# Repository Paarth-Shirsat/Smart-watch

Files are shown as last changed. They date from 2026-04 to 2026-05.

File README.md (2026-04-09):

# Smart-Watch (ESP32-PICO-D4)

A comprehensive open-source smart-watch project featuring high-end sensors, GPS integration, and a sleek hardware design. This project is built around the **ESP32-PICO-D4** System-in-Package, providing a compact yet powerful core for wearable applications.

<p align="center">
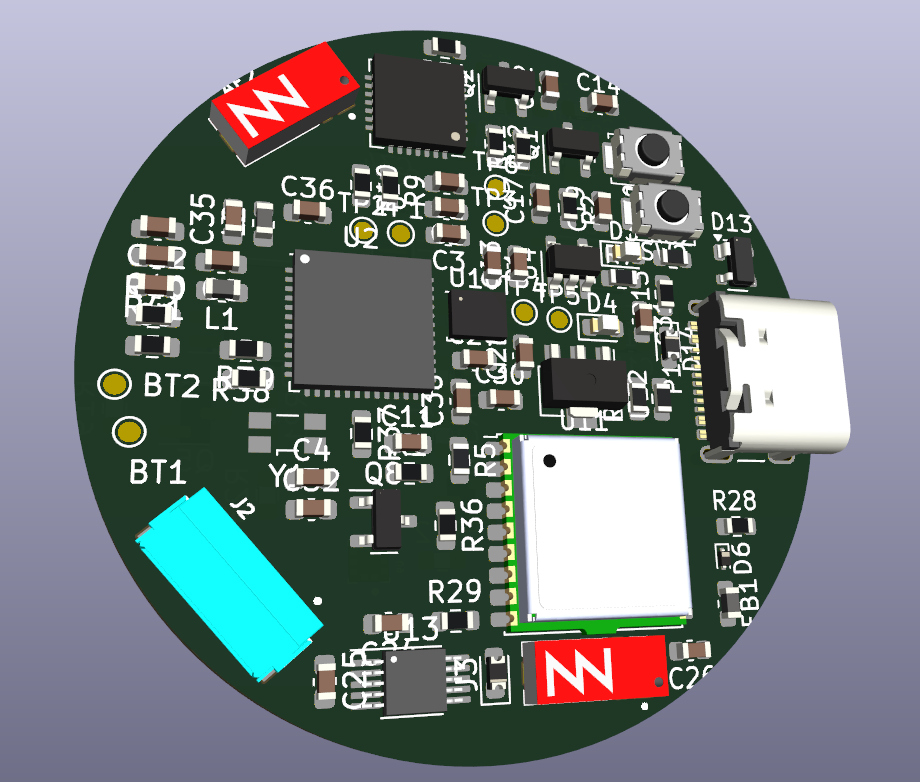
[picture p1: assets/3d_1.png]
  
</p>
<p align="center">
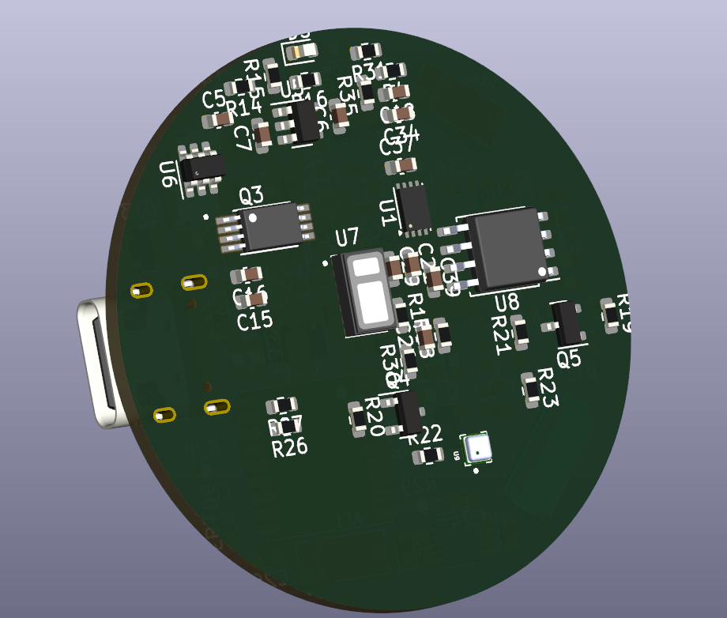
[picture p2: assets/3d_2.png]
  
</p>
## 🚀 Features

- **Core Processor**: ESP32-PICO-D4 (Dual-core, Wi-Fi & Bluetooth, integrated Flash).
- **Navigation**: u-blox **MAX-M10S** GNSS module for high-precision positioning.
- **Health Monitoring**: **MAX30102/30105** sensor for heart rate and pulse oximetry.
- **Motion Tracking**: **LSM6DSO/LSM6DS3** 6-axis IMU (Accelerometer + Gyroscope).
- **Environment**: **BMP388** barometric pressure sensor for altitude and weather tracking.
- **Haptics**: **DRV2605L** haptic driver for sophisticated vibration patterns.
- **Storage & Memory**: 
  - 128Mbit external SPI Flash (**W25Q128**).
  - 64Mbit external QSPI PSRAM (**APS6404L**).
- **Power Management**:
  - USB-C charging via **MCP73831** Li-Po charger.
  - Integrated battery protection using **AP9101C**.
  - High-efficiency LDOs for stable rail regulation.
- **Connectivity**: USB-to-UART via **CP2102N** for easy programming and debugging.

## 📂 Repository Structure

```text
├── firmware/                 # ESP-IDF based driver  implementations and test apps
│   ├── bmp388/               # Barometric sensor test code
    ├── lsm6dso_i2c/          # 6-axis IMU I2C    
    |
    ├── max30102/             # Heart rate sensor 
    └── max_m10s/             # GNSS/GPS driver and esting
├── PCB_Files/                # KiCad Hardware Design Files
│   ├── watch.kicad_sch       # Main Schematic
│   ├── watch.kicad_pcb       # PCB Layout
│   └── watch.csv             # Bill of Materials (BOM)
└── footprints_schematics/    # Custom KiCad libraries and footprints
```

## 🛠️ Hardware Setup

The hardware is designed using **KiCad**. You can find the full schematics and PCB layout in the `PCB_Files` directory.

### Key Components
- **MCU**: [ESP32-PICO-D4](https://www.espressif.com/sites/default/files/documentation/esp32-pico-d4_datasheet_en.pdf)
- **GNSS**: [u-blox MAX-M10S](https://content.u-blox.com/sites/default/files/MAX-M10S_DataSheet_UBX-20035208.pdf)
- **IMU**: [ST LSM6D3](https://www.st.com/resource/en/datasheet/lsm6ds3tr-c.pdf)
- **Pressure**: [Bosch BMP388](https://www.bosch-sensortec.com/media/boschsensortec/downloads/datasheets/bst-bmp388-ds001.pdf)

## 💻 Firmware Development

The firmware is developed using the **ESP-IDF** (Espressif IoT Development Framework).

### Prerequisites
- Install [ESP-IDF SDK](https://docs.espressif.com/projects/esp-idf/en/latest/esp32/get-started/index.html) (v4.4 or later recommended).

### Building a Component
To build and flash one of the test apps (e.g., the GPS module):
```bash
cd firmware/max_m10s
idf.py build
idf.py -p [PORT] flash monitor
```

## 🎨 Design Aesthetics
The PCB design focuses on a compact circular/watch-friendly form factor with optimized trace routing for high-speed signals (Flash/PSRAM) and sensitive analog paths (Heart Rate sensor).

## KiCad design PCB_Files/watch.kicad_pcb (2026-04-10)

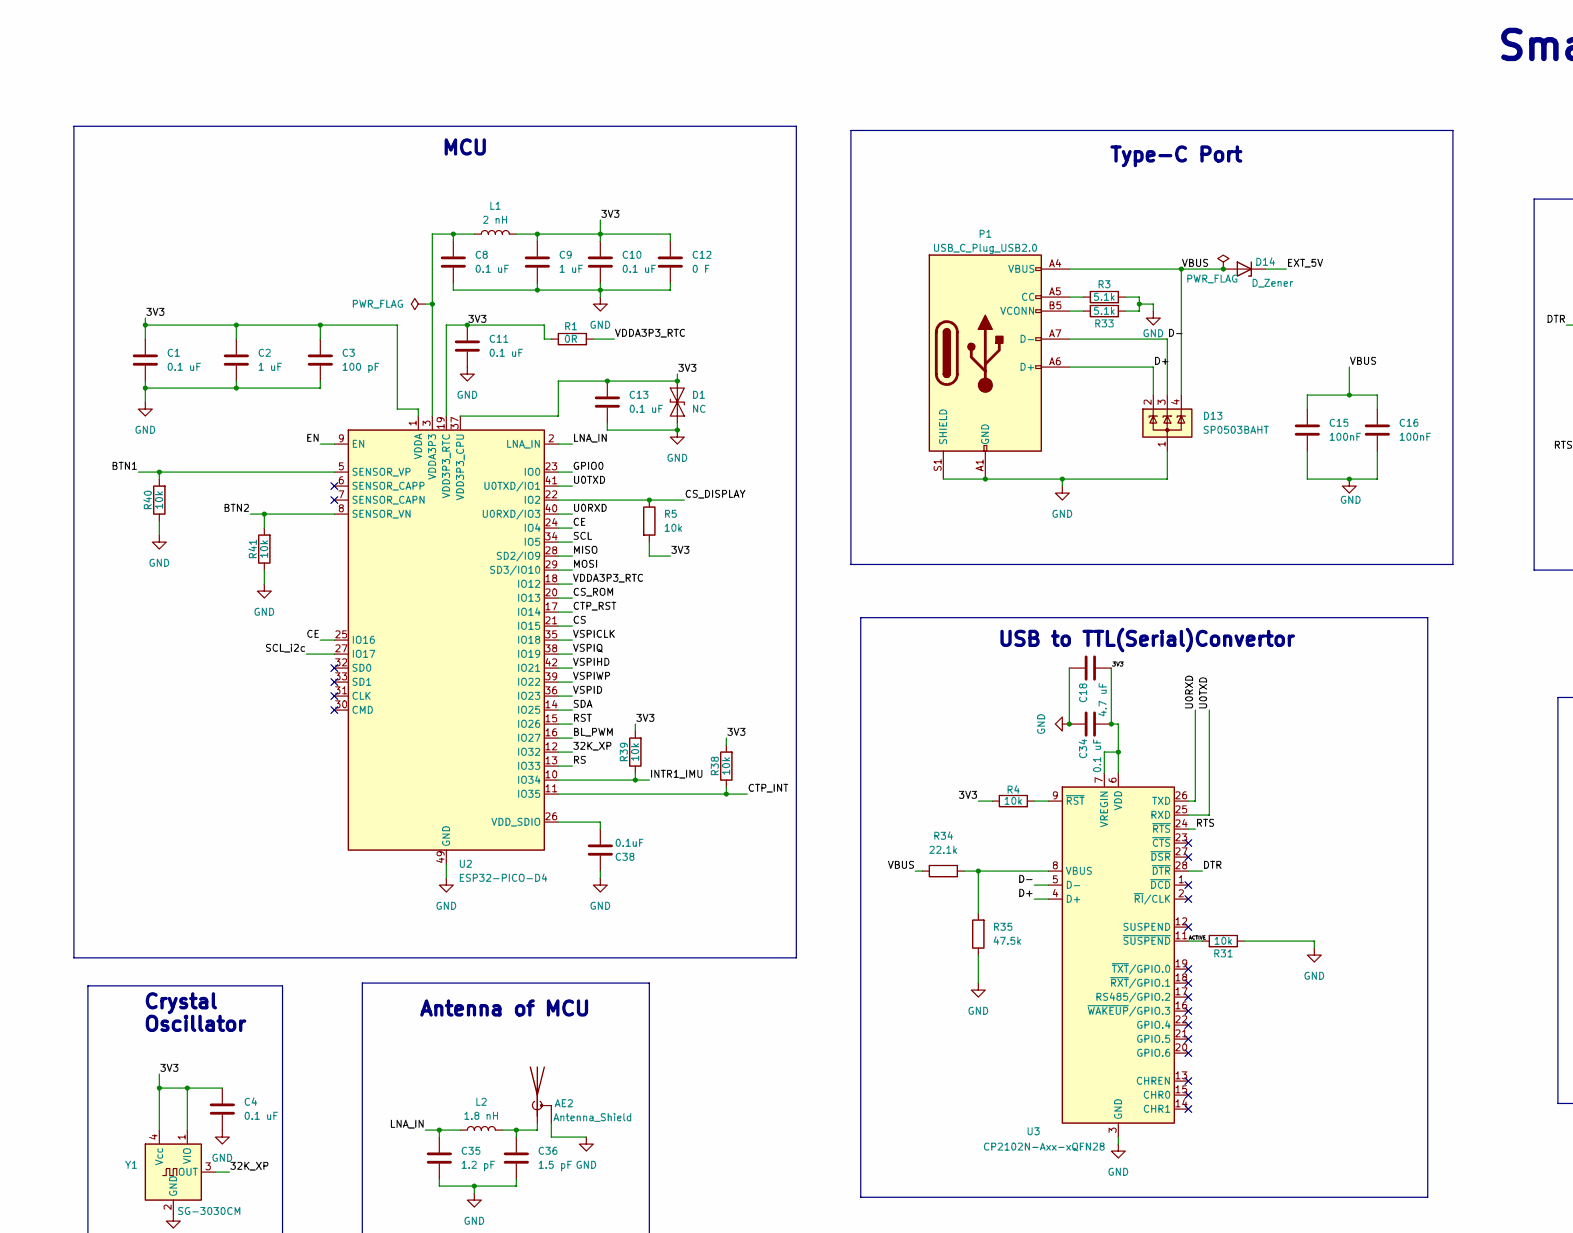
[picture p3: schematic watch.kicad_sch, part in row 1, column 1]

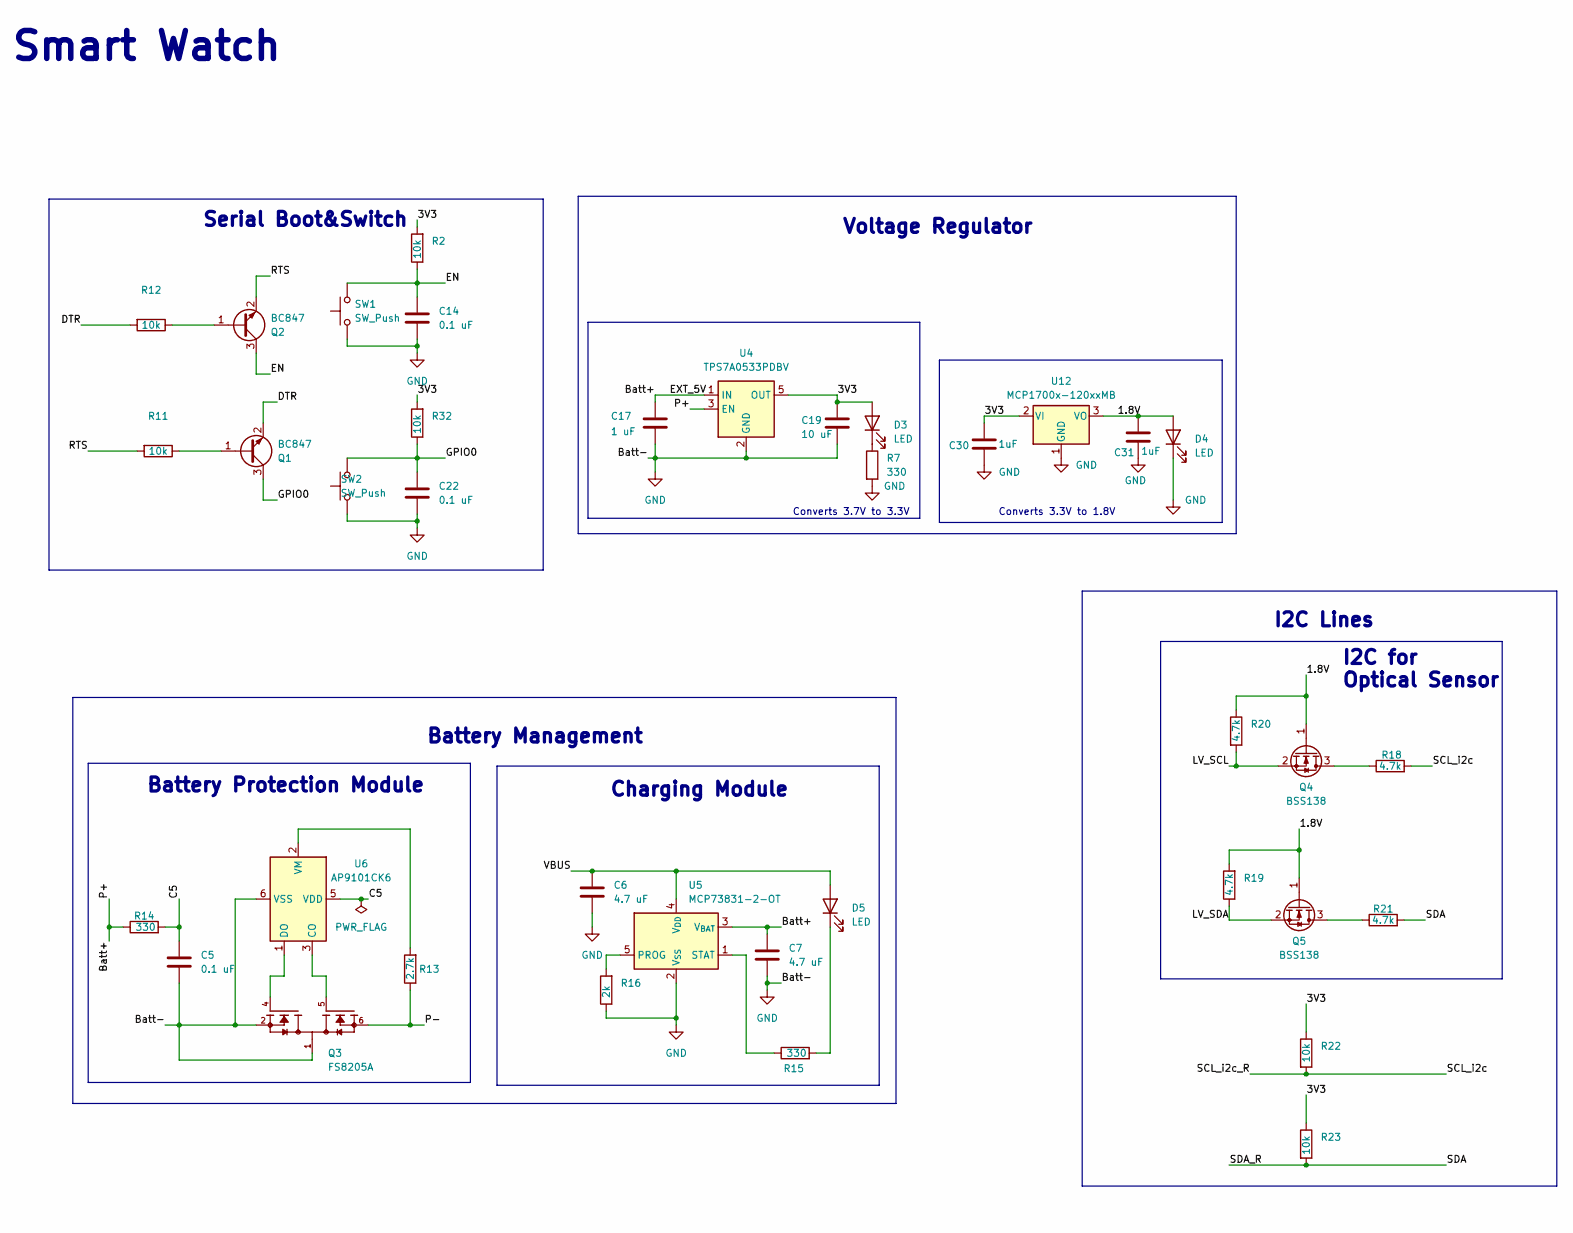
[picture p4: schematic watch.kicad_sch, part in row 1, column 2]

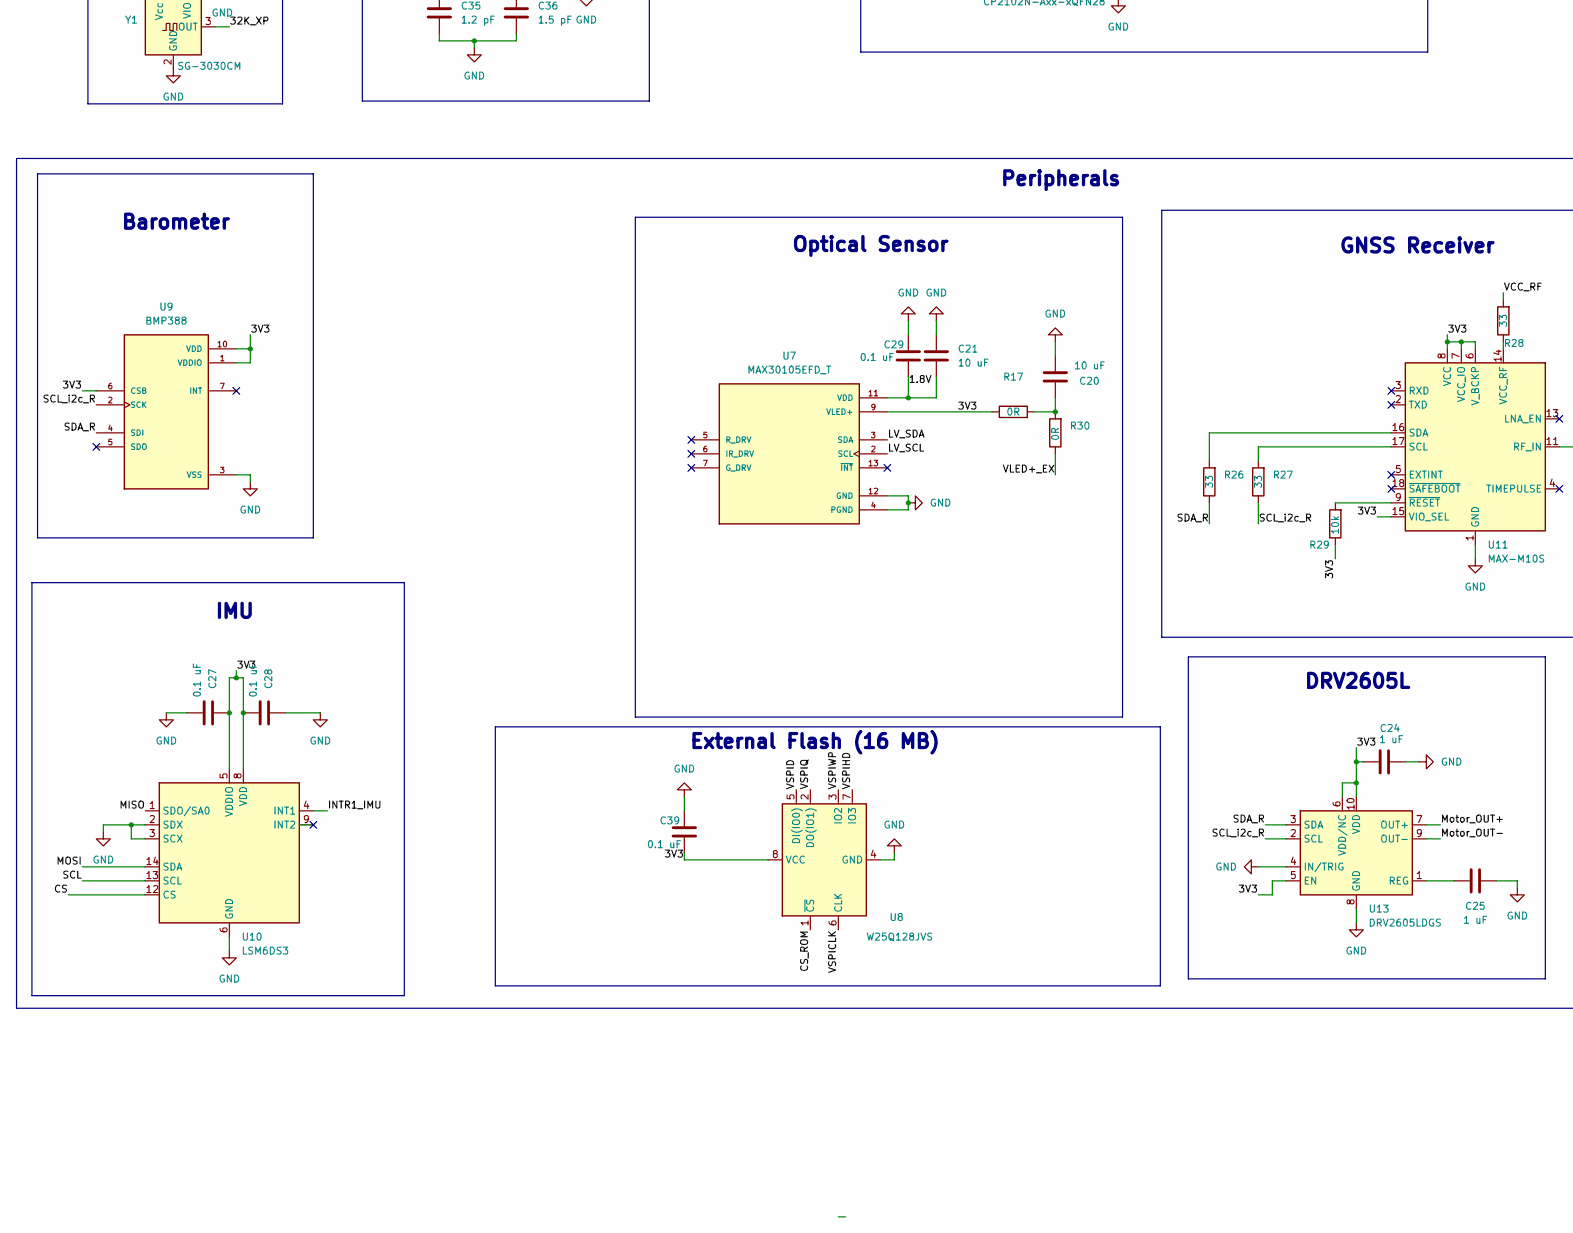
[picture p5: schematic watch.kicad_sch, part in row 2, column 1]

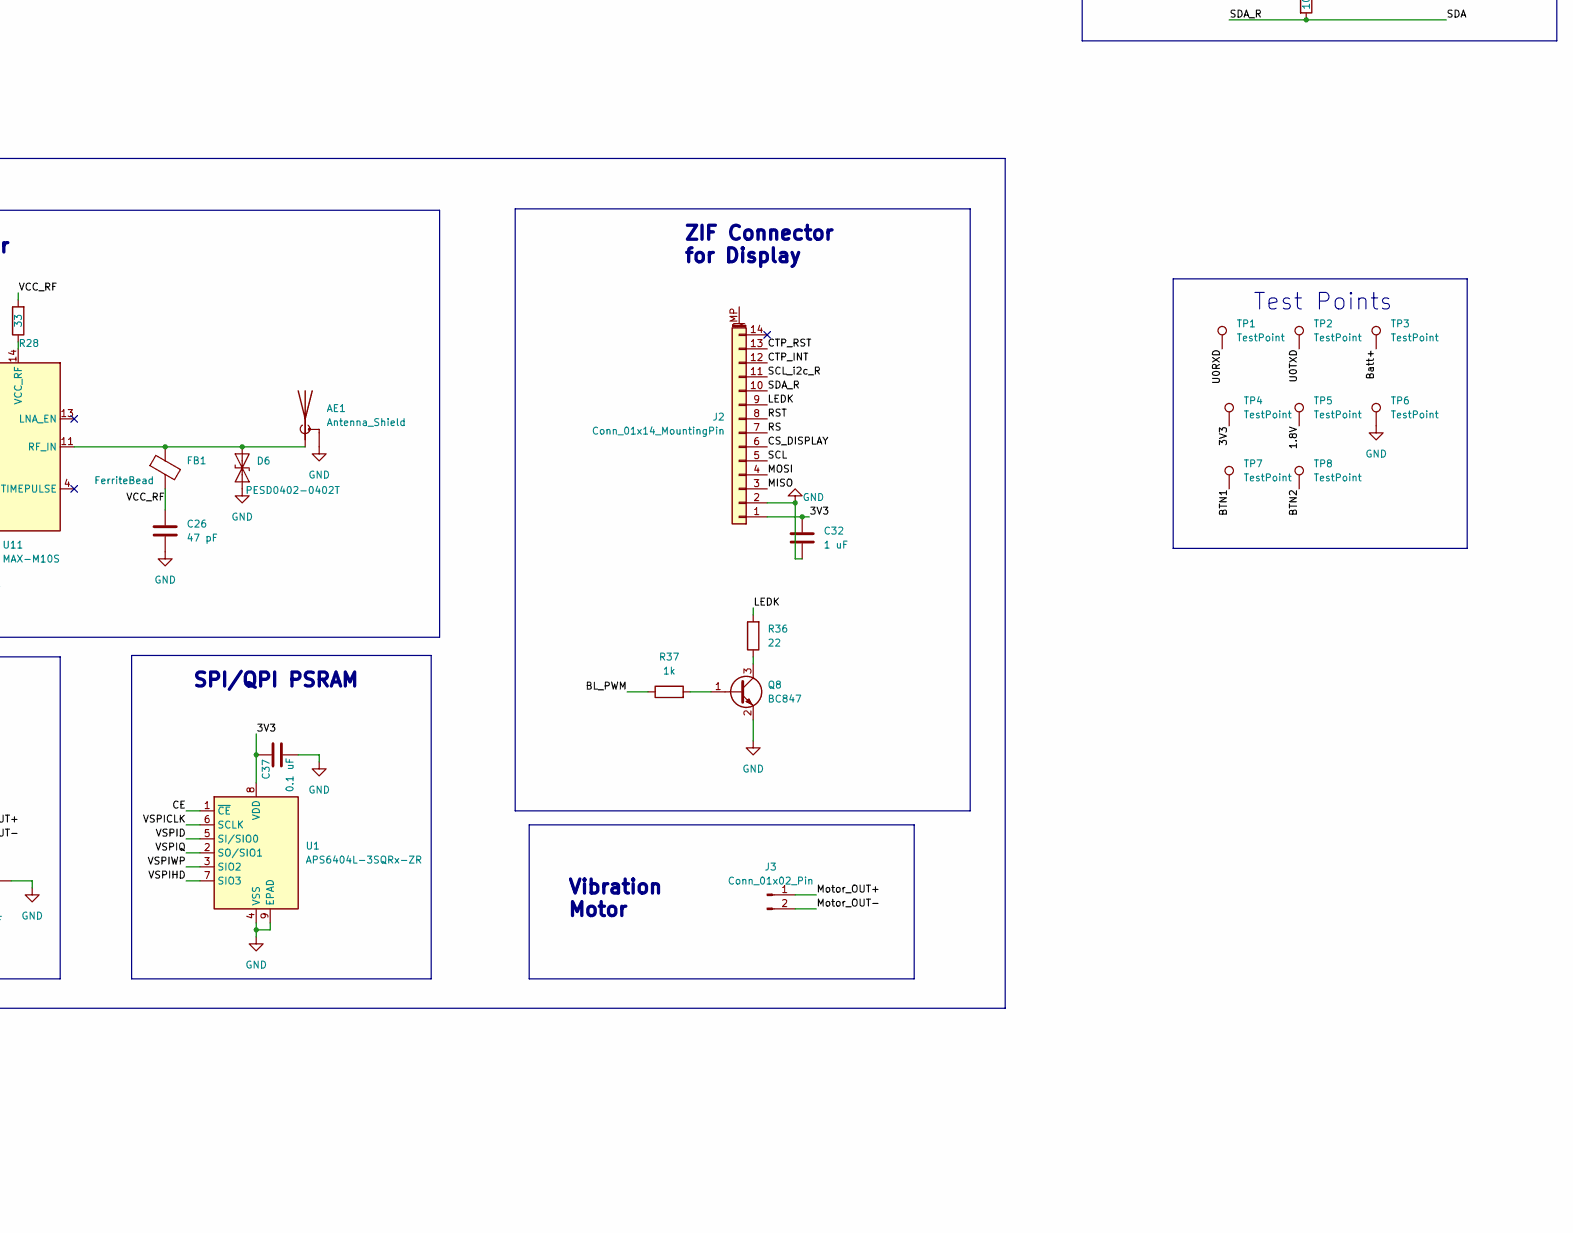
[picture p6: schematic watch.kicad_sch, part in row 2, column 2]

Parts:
AE1, AE2: Antenna_Shield; XCVR_NN03-320
C1, C4, C5, C8, C10, C11, C13, C14, C22, C27, C28, C29, C34, C37, C39: 0.1 uF; C_0603_1608Metric
C2, C9, C17, C24, C25, C32: 1 uF; C_0603_1608Metric
C3: 100 pF; C_0603_1608Metric
C6, C7, C18: 4.7 uF; C_0603_1608Metric
C12: 0 F; C_0603_1608Metric
C15, C16: 100nF; C_0603_1608Metric
C19, C20, C21: 10 uF; C_0603_1608Metric
C26: 47 pF; C_0603_1608Metric
C30, C31: 1uF; C_0603_1608Metric
C35: 1.2 pF; C_0603_1608Metric
C36: 1.5 pF; C_0603_1608Metric
C38: 0.1uF; C_0603_1608Metric
D1: NC; C_0603_1608Metric
D3, D4, D5: LED; LED_0603_1608Metric
D6: PESD0402-0402T; D_SOD-923
D13: SP0503BAHT; SOT-143
D14: D_Zener; D_0603_1608Metric
FB1: FerriteBead; L_0603_1608Metric
J2: Conn_01x14_MountingPin; HRS_FH34SRJ-14S-0.5SH_50_
J3: Conn_01x02_Pin; D_0603_1608Metric
L1: 2 nH; L_0603_1608Metric
L2: 1.8 nH; L_0603_1608Metric
P1: USB_C_Plug_USB2.0; USB_C_Receptacle_GCT_USB4105-xx-A_16P_TopMnt_Horizontal
Q1, Q2, Q8: BC847; SOT-23
Q3: FS8205A; SOP65P640X120-8N
Q4, Q5: BSS138; SOT-23
R1, R17, R30: 0R; R_0603_1608Metric
R2, R4, R5, R11, R12, R22, R23, R29, R31, R32, R38, R39, R40, R41: 10k; R_0603_1608Metric
R3, R33: 5.1k; R_0603_1608Metric
R7, R14, R15: 330; R_0603_1608Metric
R13: 2.7k; R_0603_1608Metric
R16: 2k; R_0603_1608Metric
R18, R19, R20, R21: 4.7k; R_0603_1608Metric
R26, R27, R28: 33; R_0603_1608Metric
R34: 22.1k; R_0603_1608Metric
R35: 47.5k; R_0603_1608Metric
R36: 22; R_0603_1608Metric
R37: 1k; R_0603_1608Metric
SW1, SW2: SW_Push; SW_Push_SPST_NO_Alps_SKRK
TP1, TP2, TP3, TP4, TP5, TP6, TP7, TP8: TestPoint; TestPoint_Pad_D1.0mm
U1: APS6404L-3SQRx-ZR; Winbond_USON-8-1EP_3x2mm_P0.5mm_EP0.2x1.6mm
U2: ESP32-PICO-D4; QFN-48-1EP_7x7mm_P0.5mm_EP5.3x5.3mm
U3: CP2102N-Axx-xQFN28; QFN-28-1EP_5x5mm_P0.5mm_EP3.35x3.35mm
U4: TPS7A0533PDBV; SOT-23-5
U5: MCP73831-2-OT; SOT-23-5
U6: AP9101CK6; SOT-23-6
U7: MAX30105EFD_T; 14-OESIP
U8: W25Q128JVS; SOIC-8_5.23x5.23mm_P1.27mm
U9: BMP388; PQFN50P200X200X80-10N
U10: LSM6DS3; LGA-14_3x2.5mm_P0.5mm_LayoutBorder3x4y
U11: MAX-M10S; ublox_MAX
U12: MCP1700x-120xxMB; SOT-89-3
U13: DRV2605LDGS; VSSOP-10_3x3mm_P0.5mm
Y1: SG-3030CM; Oscillator_SMD_SeikoEpson_SG3030CM

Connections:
/1.8V: C21.2, C29.2, C31.2, D4.2 (A), Q4.1 (G), Q5.1 (G), R19.2, R20.1, TP5.1, U7.11 (VDD), U12.3 (VO)
/3V3: C1.1, C2.1, C3.1, C4.1, C9.1, C10.1, C11.1, C12.1, C13.1, C18.2, C19.1, C24.1, C27.1, C28.2, C30.2, C32.1, C34.2, C37.1, C39.2, D1.2 (A2), D3.2 (A), J2.1, L1.2, R1.1, R2.2, R4.1, R5.2, R17.1, R22.1, R23.1, R29.1, R32.2, R38.2, R39.2, TP4.1, U1.8 (VDD), U2.1 (VDDA), U2.19 (VDD3P3_RTC), U2.37 (VDD3P3_CPU), U2.43 (VDDA), U2.46 (VDDA), U3.6 (VDD), U3.7 (VREGIN), U4.5 (OUT), U7.9 (VLED+), U8.8 (VCC), U9.1 (VDDIO), U9.6 (CSB), U9.10 (VDD), U10.5 (VDDIO), U10.8 (VDD), U11.6 (V_BCKP), U11.7 (VCC_IO), U11.8 (VCC), U11.15 (VIO_SEL), U12.2 (VI), U13.5 (EN), U13.6 (VDD/NC), U13.10 (VDD), Y1.1 (VIO), Y1.4 (Vcc)
/32K_XP: U2.12 (IO32), Y1.3 (OUT)
/ACTIVE: R31.2, U3.11 (~SUSPEND)
/BL_PWM: R37.1, U2.16 (IO27)
/BTN1: R40.2, TP7.1, U2.5 (SENSOR_VP)
/BTN2: R41.2, TP8.1, U2.8 (SENSOR_VN)
/Batt+: C7.1, C17.1, D14.1 (K), R14.1, TP3.1, U4.1 (IN), U4.3 (EN), U5.3 (V_{BAT})
/C5: C5.1, R14.2, U6.5 (VDD)
/CE: U1.1 (~CE), U2.24 (IO4), U2.25 (IO16)
/CS: U2.21 (IO15), U10.12 (CS)
/CS_DISPLAY: J2.6, R5.1, U2.22 (IO2)
/CS_ROM: U2.20 (IO13), U8.1 (~CS)
/CTP_INT: J2.12, R38.1, U2.11 (IO35)
/CTP_RST: J2.13, U2.17 (IO14)
/D+: D13.2 (K), P1.A6 (D+), U3.4 (D+)
/D-: D13.3 (K), P1.A7 (D-), U3.5 (D-)
/DTR: Q1.2 (E), R12.2, U3.28 (~DTR)
/EN: C14.1, Q2.3 (C), R2.1, SW1.2, U2.9 (EN)
/GPIO0: C22.1, Q1.3 (C), R32.1, SW2.2, U2.23 (IO0)
/INTR1_IMU: R39.1, U2.10 (IO34), U10.4 (INT1)
/LEDK: J2.9, R36.2
/LNA_IN: C35.1, L2.1, U2.2 (LNA_IN)
/LV_SCL: Q4.2 (S), R20.2, U7.2 (SCL)
/LV_SDA: Q5.2 (S), R19.1, U7.3 (SDA)
/MISO: J2.3, U2.28 (SD2/IO9), U10.1 (SDO/SA0)
/MOSI: J2.4, U2.29 (SD3/IO10), U10.14 (SDA)
/Motor_OUT+: J3.1, U13.7 (OUT+)
/Motor_OUT-: J3.2, U13.9 (OUT-)
/P-: Q3.6, Q3.7, R13.1
/RS: J2.7, U2.13 (IO33)
/RST: J2.8, U2.15 (IO26)
/RTS: Q2.2 (E), R11.2, U3.24 (~RTS)
/SCL: J2.5, U2.34 (IO5), U10.13 (SCL)
/SCL_i2c: J2.11, R18.2, R22.2, R27.1, U2.27 (IO17), U9.2 (SCK), U13.2 (SCL)
/SDA: J2.10, R21.2, R23.2, R26.1, U2.14 (IO25), U9.4 (SDI), U13.3 (SDA)
/U0RXD: TP1.1, U2.40 (U0RXD/IO3), U3.26 (TXD)
/U0TXD: TP2.1, U2.41 (U0TXD/IO1), U3.25 (RXD)
/VBUS: C6.1, C15.1, C16.1, D5.2 (A), D13.4 (K), D14.2 (A), P1.A4 (VBUS), P1.A9 (VBUS), P1.B4 (VBUS), P1.B9 (VBUS), R34.1, U5.4 (V_{DD})
/VCC_RF: C26.1, FB1.2, R28.2
/VDDA3P3_RTC: R1.2, U2.18 (IO12)
/VLED+_EX: R30.1
/VSPICLK: U1.6 (SCLK), U2.35 (IO18), U8.6 (CLK)
/VSPID: U1.5 (SI/SIO0), U2.36 (IO23), U8.5 (DI(IO0))
/VSPIHD: U1.7 (SIO3), U2.42 (IO21), U8.7 (IO3)
/VSPIQ: U1.2 (SO/SIO1), U2.38 (IO19), U8.2 (DO(IO1))
/VSPIWP: U1.3 (SIO2), U2.39 (IO22), U8.3 (IO2)
GND: AE1.2 (Shield), AE2.2 (Shield), C1.2, C2.2, C3.2, C4.2, C5.2, C6.2, C7.2, C8.2, C9.2, C10.2, C11.2, C12.2, C13.2, C14.2, C15.2, C16.2, C17.2, C18.1, C19.2, C20.2, C21.1, C22.2, C24.2, C25.2, C26.2, C27.2, C28.1, C29.1, C30.1, C31.1, C32.2, C34.1, C35.2, C36.2, C37.2, C38.1, C39.1, D1.1 (A1), D4.1 (K), D6.1 (A1), D13.1 (A), J2.2, P1.A1 (GND), P1.A12 (GND), P1.B1 (GND), P1.B12 (GND), P1.S1 (SHIELD), Q3.1, Q3.2, Q3.3, Q3.8, Q8.2 (E), R3.2, R7.2, R16.1, R31.1, R33.2, R35.1, R40.1, R41.1, SW1.1, SW2.1, TP6.1, U1.4 (VSS), U1.9 (EPAD), U2.49 (GND), U3.3 (GND), U3.29 (GND), U4.2 (GND), U5.2 (V_{SS}), U6.6 (VSS), U7.4 (PGND), U7.12 (GND), U8.4 (GND), U9.3 (VSS), U9.8 (VSS), U9.9 (VSS), U10.2 (SDX), U10.3 (SCX), U10.6 (GND), U10.7 (GND), U11.1 (GND), U11.10 (GND), U11.12 (GND), U12.1 (GND), U13.4 (IN/TRIG), U13.8 (GND), Y1.2 (GND)
unnamed: AE1.3 (A), D6.2 (A2), FB1.1, U11.11 (RF_IN)
unnamed: AE2.3 (A), C36.1, L2.2
unnamed: C8.1, L1.1, U2.3 (VDDA3P3), U2.4 (VDDA3P3)
unnamed: C20.1, R17.2, R30.2
unnamed: D3.1 (K), R7.1
unnamed: D5.1 (K), R15.2
unnamed: P1.A5 (CC), R3.1
unnamed: P1.B5 (VCONN), R33.1
unnamed: Q1.1 (B), R11.1
unnamed: Q2.1 (B), R12.1
unnamed: Q4.3 (D), R18.1
unnamed: Q5.3 (D), R21.1
unnamed: Q8.1 (B), R37.2
unnamed: Q8.3 (C), R36.1
unnamed: C38.2, U2.26 (VDD_SDIO)
unnamed: R34.2, R35.2, U3.8 (VBUS)
unnamed: R4.2, U3.9 (~RST)
unnamed: R16.2, U5.5 (PROG)
unnamed: R15.1, U5.1 (STAT)
unnamed: Q3.5, U6.3 (CO)
unnamed: Q3.4, U6.1 (DO)
unnamed: R13.2, U6.2 (VM)
unnamed: R27.2, U11.17 (SCL)
unnamed: R26.2, U11.16 (SDA)
unnamed: R28.1, U11.14 (VCC_RF)
unnamed: R29.2, U11.9 (~RESET)
unnamed: C25.1, U13.1 (REG)

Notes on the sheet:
USB to TTL(Serial)Convertor
External Flash (16 MB)
DRV2605L
Battery Protection Module
Optical Sensor
Voltage Regulator
Smart Watch
ZIF Connector for Display
Converts 3.3V to 1.8V
MCU
I2C Lines
Battery Management
SPI/QPI PSRAM
GNSS Receiver
Type-C Port
Antenna of MCU
Vibration Motor
IMU
Serial Boot&Switch
Converts 3.7V to 3.3V
Crystal Oscillator
Charging Module
Peripherals
Test Points
Barometer
I2C for Optical Sensor

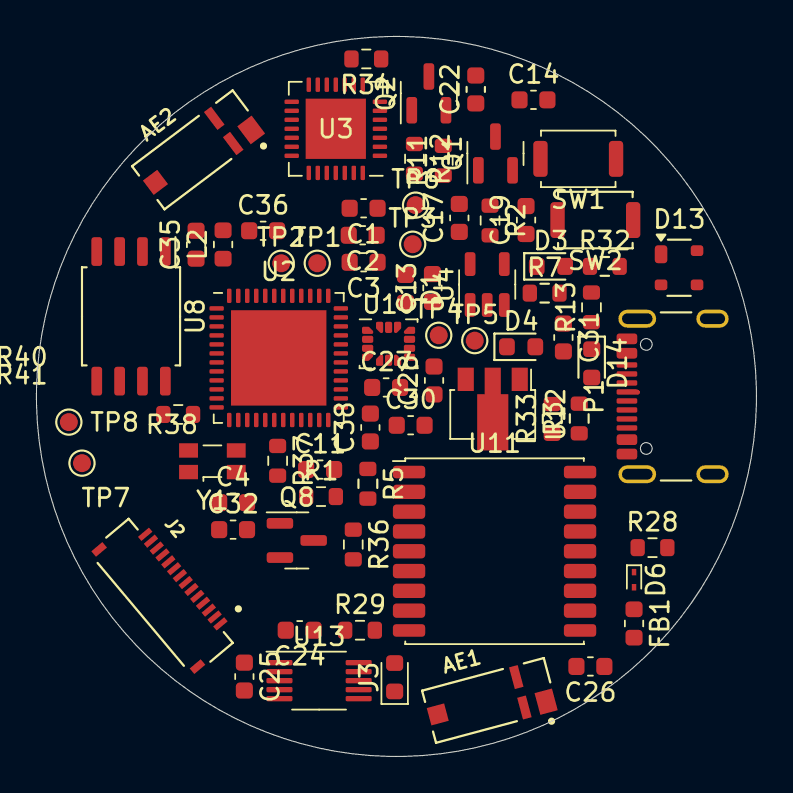
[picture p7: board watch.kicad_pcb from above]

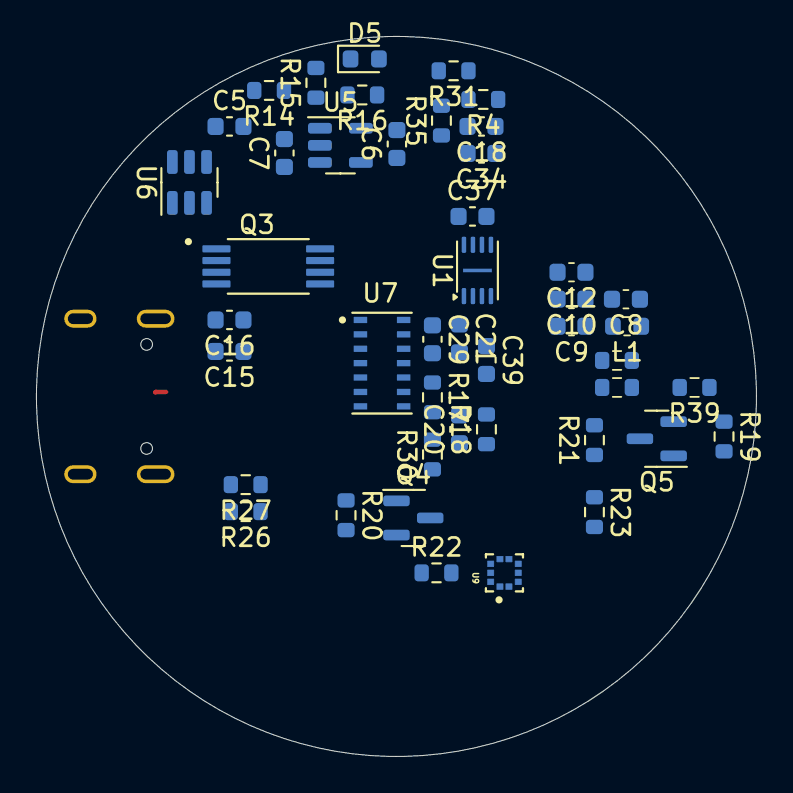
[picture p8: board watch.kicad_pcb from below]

Board: 4 copper layers, 40.0 x 40.0 mm, 117 parts (45 on the bottom side), 74 nets.

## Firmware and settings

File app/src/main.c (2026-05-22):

#include <zephyr/kernel.h>
#include <zephyr/logging/log.h>
#include <zephyr/zbus/zbus.h>
#include "events/periodic_events.h"
#include "events/imu_events.h"
#include "events/baro_events.h"

LOG_MODULE_REGISTER(main, LOG_LEVEL_INF);

static void on_imu_data(const struct zbus_channel *chan)
{
    const struct imu_data_event *e = zbus_chan_const_msg(chan);
    LOG_INF("IMU | Accel: %.2f %.2f %.2f | Gyro: %.2f %.2f %.2f",
        (double)e->accel_x, (double)e->accel_y, (double)e->accel_z,
        (double)e->gyro_x,  (double)e->gyro_y,  (double)e->gyro_z);
}

static void on_baro_data(const struct zbus_channel *chan)
{
    const struct baro_data_event *e = zbus_chan_const_msg(chan);
    LOG_INF("BARO | %.2f hPa | %.1f m | %.2f C",
        (double)e->pressure_hpa,
        (double)e->altitude_m,
        (double)e->temperature_c);
}

ZBUS_LISTENER_DEFINE(main_imu_listener,  on_imu_data);
ZBUS_LISTENER_DEFINE(main_baro_listener, on_baro_data);
ZBUS_CHAN_ADD_OBS(imu_data_chan,  main_imu_listener,  0);
ZBUS_CHAN_ADD_OBS(baro_data_chan, main_baro_listener, 0);

int main(void)
{
    LOG_INF("Zephyr RTOS Booting on Custom Smartwatch...");
    return 0;
}

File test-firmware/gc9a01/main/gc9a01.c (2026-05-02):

#include <stdio.h>
#include <string.h>
#include "freertos/FreeRTOS.h"
#include "freertos/task.h"
#include "driver/spi_master.h"
#include "driver/i2c.h"
#include "driver/gpio.h"
#include "esp_log.h"
#include "esp_heap_caps.h"
#include <math.h>

static const char *TAG = "ROUND_LCD";

/* ── Pin definitions ──────────────────────────────────────────────────────── */
#define LCD_SPI_HOST    SPI2_HOST
#define LCD_PIN_SCLK    18
#define LCD_PIN_MOSI    23
#define LCD_PIN_CS       5
#define LCD_PIN_DC       2
#define LCD_PIN_RST      4
#define LCD_PIN_BL      15

#define TOUCH_I2C_PORT  I2C_NUM_0
#define TOUCH_PIN_SDA   21
#define TOUCH_PIN_SCL   22
#define TOUCH_PIN_INT   36   /* set to -1 to disable */
#define TOUCH_PIN_RST   27   /* set to -1 to share with LCD RST */
#define TOUCH_I2C_ADDR  0x15 /* CST816S default address */
#define TOUCH_I2C_HZ    400000

/* ── LCD geometry ─────────────────────────────────────────────────────────── */
#define LCD_WIDTH   240
#define LCD_HEIGHT  240

/* ── SPI speed ────────────────────────────────────────────────────────────── */
#define LCD_SPI_HZ  (40 * 1000 * 1000)  /* 40 MHz */

/* ── Colour helpers (RGB565) ──────────────────────────────────────────────── */
#define RGB565(r, g, b) \
    ((uint16_t)(((r) & 0xF8) << 8) | (((g) & 0xFC) << 3) | ((b) >> 3))

#define COL_BLACK   0x0000
#define COL_WHITE   0xFFFF
#define COL_RED     RGB565(255,   0,   0)
#define COL_GREEN   RGB565(  0, 255,   0)
#define COL_BLUE    RGB565(  0,   0, 255)
#define COL_YELLOW  RGB565(255, 255,   0)
#define COL_CYAN    RGB565(  0, 255, 255)

//Display Driver

static spi_device_handle_t s_spi;

/* Send a single command byte */
static void lcd_cmd(uint8_t cmd)
{
    gpio_set_level(LCD_PIN_DC, 0);
    spi_transaction_t t = {
        .length = 8,
        .tx_buffer = &cmd,
        .flags = 0,
    };
    spi_device_polling_transmit(s_spi, &t);
}

/* Send a single data byte */
static void lcd_data(uint8_t data)
{
    gpio_set_level(LCD_PIN_DC, 1);
    spi_transaction_t t = {
        .length = 8,
        .tx_buffer = &data,
        .flags = 0,
    };
    spi_device_polling_transmit(s_spi, &t);
}

/* Send a buffer (data mode) */
static void lcd_data_buf(const uint8_t *buf, size_t len)
{
    if (!len) return;
    gpio_set_level(LCD_PIN_DC, 1);
    spi_transaction_t t = {
        .length = len * 8,
        .tx_buffer = buf,
        .flags = 0,
    };
    spi_device_polling_transmit(s_spi, &t);
}

/* Hardware reset */
static void lcd_reset(void)
{
    gpio_set_level(LCD_PIN_RST, 0);
    vTaskDelay(pdMS_TO_TICKS(100));
    gpio_set_level(LCD_PIN_RST, 1);
    vTaskDelay(pdMS_TO_TICKS(120));
}

/* GC9A01 full initialisation sequence */
static void gc9a01_init(void)
{
    lcd_reset();

    lcd_cmd(0xEF);
    lcd_cmd(0xEB); lcd_data(0x14);
    lcd_cmd(0xFE);
    lcd_cmd(0xEF);

    lcd_cmd(0xEB); lcd_data(0x14);
    lcd_cmd(0x84); lcd_data(0x40);
    lcd_cmd(0x85); lcd_data(0xFF);
    lcd_cmd(0x86); lcd_data(0xFF);
    lcd_cmd(0x87); lcd_data(0xFF);
    lcd_cmd(0x88); lcd_data(0x0A);
    lcd_cmd(0x89); lcd_data(0x21);
    lcd_cmd(0x8A); lcd_data(0x00);
    lcd_cmd(0x8B); lcd_data(0x80);
    lcd_cmd(0x8C); lcd_data(0x01);
    lcd_cmd(0x8D); lcd_data(0x01);
    lcd_cmd(0x8E); lcd_data(0xFF);
    lcd_cmd(0x8F); lcd_data(0xFF);

    lcd_cmd(0xB6);
    lcd_data(0x00);
    lcd_data(0x20);          /* display direction */

    lcd_cmd(0x3A); lcd_data(0x05); /* 16-bit (RGB565) */

    lcd_cmd(0x90);
    lcd_data(0x08); lcd_data(0x08);
    lcd_data(0x08); lcd_data(0x08);

    lcd_cmd(0xBD); lcd_data(0x06);
    lcd_cmd(0xBC); lcd_data(0x00);

    lcd_cmd(0xFF);
    lcd_data(0x60); lcd_data(0x01); lcd_data(0x04);

    lcd_cmd(0xC3); lcd_data(0x13);
    lcd_cmd(0xC4); lcd_data(0x13);
    lcd_cmd(0xC9); lcd_data(0x22);
    lcd_cmd(0xBE); lcd_data(0x11);

    lcd_cmd(0xE1);
    lcd_data(0x10); lcd_data(0x0E);

    lcd_cmd(0xDF);
    lcd_data(0x21); lcd_data(0x0C); lcd_data(0x02);

    /* Gamma */
    lcd_cmd(0xF0);
    lcd_data(0x45); lcd_data(0x09); lcd_data(0x08);
    lcd_data(0x08); lcd_data(0x26); lcd_data(0x2A);

    lcd_cmd(0xF1);
    lcd_data(0x43); lcd_data(0x70); lcd_data(0x72);
    lcd_data(0x36); lcd_data(0x37); lcd_data(0x6F);

    lcd_cmd(0xF2);
    lcd_data(0x45); lcd_data(0x09); lcd_data(0x08);
    lcd_data(0x08); lcd_data(0x26); lcd_data(0x2A);

    lcd_cmd(0xF3);
    lcd_data(0x43); lcd_data(0x70); lcd_data(0x72);
    lcd_data(0x36); lcd_data(0x37); lcd_data(0x6F);

    lcd_cmd(0xED);
    lcd_data(0x1B); lcd_data(0x0B);

    lcd_cmd(0xAE); lcd_data(0x77);
    lcd_cmd(0xCD); lcd_data(0x63);

    lcd_cmd(0x70);
    lcd_data(0x07); lcd_data(0x07); lcd_data(0x04);
    lcd_data(0x0E); lcd_data(0x0F); lcd_data(0x09);
    lcd_data(0x07); lcd_data(0x08); lcd_data(0x03);

    lcd_cmd(0xE8); lcd_data(0x34);

    lcd_cmd(0x62);
    lcd_data(0x18); lcd_data(0x0D); lcd_data(0x71);
    lcd_data(0xED); lcd_data(0x70); lcd_data(0x70);
    lcd_data(0x18); lcd_data(0x0F); lcd_data(0x71);
    lcd_data(0xEF); lcd_data(0x70); lcd_data(0x70);

    lcd_cmd(0x63);
    lcd_data(0x18); lcd_data(0x11); lcd_data(0x71);
    lcd_data(0xF1); lcd_data(0x70); lcd_data(0x70);
    lcd_data(0x18); lcd_data(0x13); lcd_data(0x71);
    lcd_data(0xF3); lcd_data(0x70); lcd_data(0x70);

    lcd_cmd(0x64);
    lcd_data(0x28); lcd_data(0x29); lcd_data(0xF1);
    lcd_data(0x01); lcd_data(0xF1); lcd_data(0x00);
    lcd_data(0x07);

    lcd_cmd(0x66);
    lcd_data(0x3C); lcd_data(0x00); lcd_data(0xCD);
    lcd_data(0x67); lcd_data(0x45); lcd_data(0x45);
    lcd_data(0x10); lcd_data(0x00); lcd_data(0x00);
    lcd_data(0x00);

    lcd_cmd(0x67);
    lcd_data(0x00); lcd_data(0x3C); lcd_data(0x00);
    lcd_data(0x00); lcd_data(0x00); lcd_data(0x01);
    lcd_data(0x54); lcd_data(0x10); lcd_data(0x32);
    lcd_data(0x98);

    lcd_cmd(0x74);
    lcd_data(0x10); lcd_data(0x85); lcd_data(0x80);
    lcd_data(0x00); lcd_data(0x00); lcd_data(0x4E);
    lcd_data(0x00);

    lcd_cmd(0x98);
    lcd_data(0x3E); lcd_data(0x07);

    lcd_cmd(0x35); /* Tearing effect ON */
    lcd_cmd(0x21); /* Inversion ON (needed for correct colours) */

    lcd_cmd(0x11); /* Sleep OUT */
    vTaskDelay(pdMS_TO_TICKS(120));
    lcd_cmd(0x29); /* Display ON */
    vTaskDelay(pdMS_TO_TICKS(20));
}

/* Set address window for subsequent pixel writes */
static void lcd_set_window(uint16_t x0, uint16_t y0, uint16_t x1, uint16_t y1)
{
    lcd_cmd(0x2A);  /* Column address */
    lcd_data(x0 >> 8); lcd_data(x0 & 0xFF);
    lcd_data(x1 >> 8); lcd_data(x1 & 0xFF);

    lcd_cmd(0x2B);  /* Row address */
    lcd_data(y0 >> 8); lcd_data(y0 & 0xFF);
    lcd_data(y1 >> 8); lcd_data(y1 & 0xFF);

    lcd_cmd(0x2C);  /* Memory write */
}
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

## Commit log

2026-02-06 MCU schematics uploaded
    [watch.kicad_pcb, watch.kicad_sch]
2026-02-12 Schematics Updated
    [watch.kicad_sch]
2026-02-12 Connected few peripherals and formatting
    [watch.kicad_sch]
2026-02-18 Added Sensors
    [watch.kicad_sch]
2026-02-19 Added Connections for Barometer, GNSS, Optical Sensor
    [watch.kicad_sch]
2026-03-01 Schematics Completed
    [watch.kicad_sch]
2026-03-16 Verified and corrected schematics
    [watch.kicad_sch]
2026-03-21 Added custom footprint library and assigned footprints
    [watch.kicad_pcb, watch.kicad_sch]
2026-03-26 Set trace widths
    [watch.kicad_pcb]
2026-04-01 Move custom footprints into PCB_Files and update library table
    Relocated footprints.pretty/ from project root into PCB_Files/ to keep all PCB-related assets together. Added new SOIC-8 footprint and updated fp-lib-table to point to the new path.
2026-04-01 Update PCB layout and project settings
    [watch.kicad_pcb]
2026-04-07 Changes in schematics
    [watch.kicad_pcb, watch.kicad_sch]
2026-04-07 Added new ZIF connector footprint and made changes in schematics
2026-04-08 Adding missing footprints and making cAD
    [watch.kicad_pcb, watch.kicad_sch]
2026-04-10 changed place of some components and fixed antenna
    [watch.kicad_pcb, watch.kicad_sch]
2026-05-02 Initialised Zephyr with custom board definition
    This commit establishes the foundational firmware structure for the
    smartwatch project, migrating from ESP-IDF test firmware to a proper
    Zephyr RTOS application. Board will be updated to ESP32-PICO-D4 DTS
    when moving to final PCB.
